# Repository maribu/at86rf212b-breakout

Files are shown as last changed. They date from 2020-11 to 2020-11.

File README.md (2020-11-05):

AT86RF212B Breakout
===================

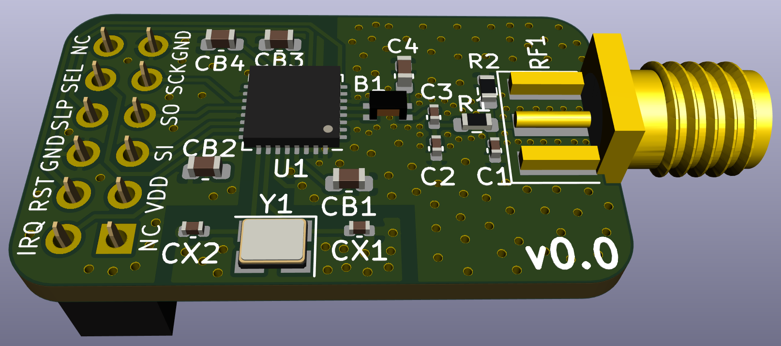
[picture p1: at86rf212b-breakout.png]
Image of an AT86RF212B Breakout Board


This Repository contains an AT86RF212B breakout board that uses the basic
application schematic given in Section 5.1 "Basic Application Schematic" on
page 11 of the AT86RF212B datasheet (02/2015), with two differences:

1. The optional clock output is omitted
2. The sub-gigahertz antenna circuit from the [AT86RF215-XPRO](https://static5.arrow.com/pdfs/2015/6/30/10/21/54/282/atm_/manual/251atreb215-xpro_design_documentation.pdf)
   is used instead, but without shielding

This board is intentionally pin compatible with the openlabs RPI 802.15.4
radio. But note that the AT86RF212B differs from the AT86RF233 used in the
openlabs RPI 802.15.4 radio not only in the frequency band, but also behaves
slightly different. Thus, a driver for the AT86RF233 will not work unmodified
for the AT86RF212B.

WARNING
=======

1. The PCB contains no shielding for the RF filter, which will result in lower
   sensitivity and higher noise in the transmitted signal compared to e.g. the
   AT86RF215-XPRO reference design.
2. It is highly recommended to not order PCBs based on this design as of now.
   This design has never been tested.
3. The SMA connector for the antenna and the 2 x 6 pins 2.54 mm female pin
   header need to be hand soldered and are not part of the generated BOM.
4. There is absolutely no warranty.

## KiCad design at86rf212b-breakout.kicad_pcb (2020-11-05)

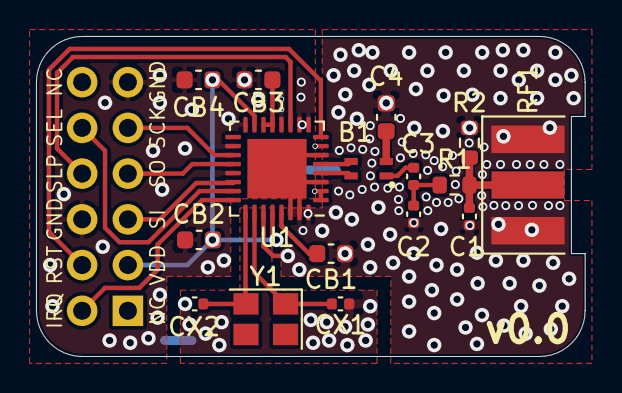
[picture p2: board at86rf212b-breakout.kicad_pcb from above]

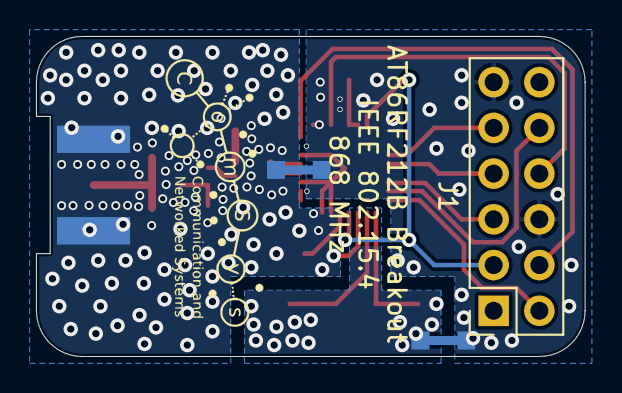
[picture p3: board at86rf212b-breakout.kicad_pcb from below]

Board: 2 copper layers, 30.5 x 17.8 mm, 19 parts (3 on the bottom side), 21 nets.

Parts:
B1: ATB2012-75011-T000
C1, C2: 2.2 pF; C_0402_1005Metric
C3: 15 pF; C_0402_1005Metric
C4: 8.2 pF; C_0603_1608Metric
CB1, CB2, CB3, CB4: 1 µF; C_0603_1608Metric
CX1, CX2: 12 pF; C_0402_1005Metric
J1: RPi Header; PinSocket_2x06_P2.54mm_Vertical
R1: 0 Ω; R_0603_1608Metric
R2: 10 kΩ; R_0603_1608Metric
R3, R4: 0 Ω; R0
RF1: Antenna; Connector-SMA
U1: AT86RF212B-ZU; QFN-32-1EP_5x5mm_P0.5mm_EP3.3x3.3mm
Y1: 16 MHz; Crystal_SMD_TXC_7M-4Pin_3.2x2.5mm

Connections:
/ANT: C1.1, R1.2, R2.1, RF1.1
/ANT': C2.1, C3.2, R1.1
/ANT'': B1.1, C3.1
/AVDD: CB1.2, U1.29
/Balun_GND: B1.2, C4.1
/DVDD: CB3.2, U1.13, U1.14
/IRQ: J1.2, U1.24
/MISO: J1.7, U1.20
/MOSI: J1.5, U1.22
/RFN: B1.3, U1.5
/RFP: B1.4, U1.4
/RST: J1.4, U1.8
/SCLK: J1.9, U1.19
/SEL: J1.10, U1.23
/SLP_TR: J1.8, U1.11
/XTAL1: CX1.2, U1.26, Y1.1
/XTAL2: CX2.2, U1.25, Y1.2
GND: CB2.1, CB3.1, CB4.1, J1.6, J1.11, R3.2, R4.2, U1.1, U1.2, U1.7, U1.9, U1.10, U1.12, U1.16, U1.18, U1.21
GND2: CX1.1, CX2.1, R3.1
GNDA: C1.2, C2.2, C4.2, CB1.1, R2.2, R4.1, RF1.2, U1.3, U1.6, U1.27, U1.30, U1.31, U1.32, U1.33
VDD: CB2.2, CB4.2, J1.3, U1.15, U1.28
